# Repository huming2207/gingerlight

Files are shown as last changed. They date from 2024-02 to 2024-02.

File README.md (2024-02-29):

# GingerLight

Yet another CN5816-based LED boost driver board design for 36v 40w COB LED, like CREE CXB2540/3040/3540.

## Usage

- Provide a 20v, 2A DC input (e.g. from a USB PD charger)
- Hook up a 36v 40w LED, like CREE CXB2540/3040/3540 (I've tested with CREE CXB2540 for now), remember to put on a heatsink or otherwise it may become a bit smoky!
- It should work now

## Fine adjustments

- According to CN5816's official datasheet and component calculator:
- When `Vin` = **20v**, `Vled` = **36v**, `Iout` = **0.8A**:
  - 
  - If Vled goes too high, try reducing R1 to 4260kohm
- If you don't want it to be that bright, or you can't afford a big heatsink, then try increasing `R6` (the `Rsw`) to something like 0.2ohm.

## Caveats

According to Consonance FAE, when calculating the resistor divider for voltage threshold reference, the `Vout` here means `Vin` + `Vled`:



For example, my `Vin` is 20v, `Vled` (the LED's `Vf`) is 36v, then `Vout` needs to be 56v, not 36v.

## License 

CC-BY-NC-SA 4.0

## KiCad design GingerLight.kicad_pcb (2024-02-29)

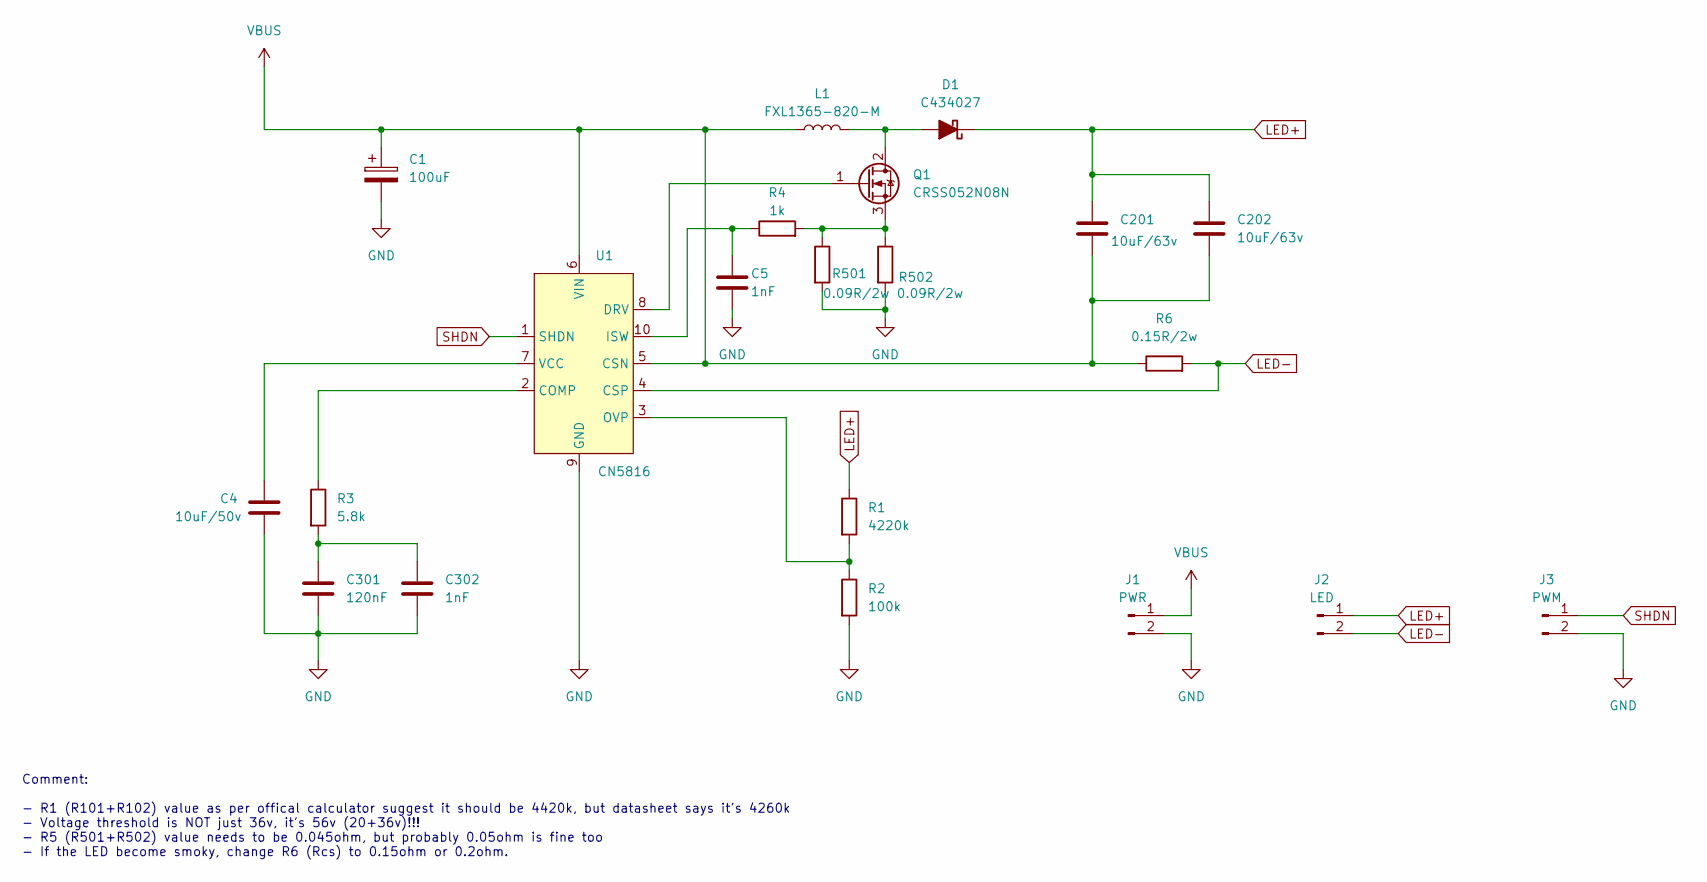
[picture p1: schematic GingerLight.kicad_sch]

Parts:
C1: 100uF; CP_Elec_8x10
C4: 10uF/50v; C_1206_3216Metric_Pad1.33x1.80mm_HandSolder
C5, C302: 1nF; C_0603_1608Metric_Pad1.08x0.95mm_HandSolder
C201, C202: 10uF/63v; C_1210_3225Metric_Pad1.33x2.70mm_HandSolder
C301: 120nF; C_0603_1608Metric_Pad1.08x0.95mm_HandSolder
D1: C434027; D_SMA
J1: PWR; PinHeader_1x02_P2.54mm_Vertical
J2: LED; PinHeader_1x02_P2.54mm_Vertical
J3: PWM; PinHeader_1x02_P2.54mm_Vertical
L1: FXL1365-820-M; L_TaiTech_TMPC1265_13.5x12.5mm
Q1: CRSS052N08N; TO-263-2
R1: 4220k; R_0603_1608Metric_Pad0.98x0.95mm_HandSolder
R2: 100k; R_0603_1608Metric_Pad0.98x0.95mm_HandSolder
R3: 5.8k; R_0603_1608Metric_Pad0.98x0.95mm_HandSolder
R4: 1k; R_0603_1608Metric_Pad0.98x0.95mm_HandSolder
R6: 0.15R/2w; R_2512_6332Metric_Pad1.40x3.35mm_HandSolder
R501, R502: 0.09R/2w; R_2512_6332Metric_Pad1.40x3.35mm_HandSolder
U1: CN5816; SSOP-10_3.9x4.9mm_P1.00mm

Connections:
GND: C1.2, C4.2, C5.2, C301.2, C302.2, J1.2, J3.2, R2.2, R501.2, R502.2, U1.9 (GND)
LED+: C201.1, C202.1, D1.1 (K), J2.1, R1.1
LED-: J2.2, R6.2, U1.4 (CSP)
unnamed: C301.1, C302.1, R3.2
unnamed: D1.2 (A), L1.2, Q1.2 (D)
unnamed: Q1.1 (G), U1.8 (DRV)
unnamed: Q1.3 (S), R4.2, R501.1, R502.1
unnamed: R3.1, U1.2 (COMP)
unnamed: C5.1, R4.1, U1.10 (ISW)
unnamed: R1.2, R2.1, U1.3 (OVP)
unnamed: C4.1, U1.7 (VCC)
SHDN: J3.1, U1.1 (SHDN)
VBUS: C1.1, C201.2, C202.2, J1.1, L1.1, R6.1, U1.5 (CSN), U1.6 (VIN)

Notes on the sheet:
Comment: - R1 (R101+R102) value as per offical calculator suggest it should be 4420k, but datasheet says it's 4260k - Voltage threshold is NOT just 36v, it's 56v (20+36v)!!! - R5 (R501+R502) value needs to be 0.045ohm, but probably 0.05ohm is fine too - If the LED become smoky, change R6 (Rcs) to 0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

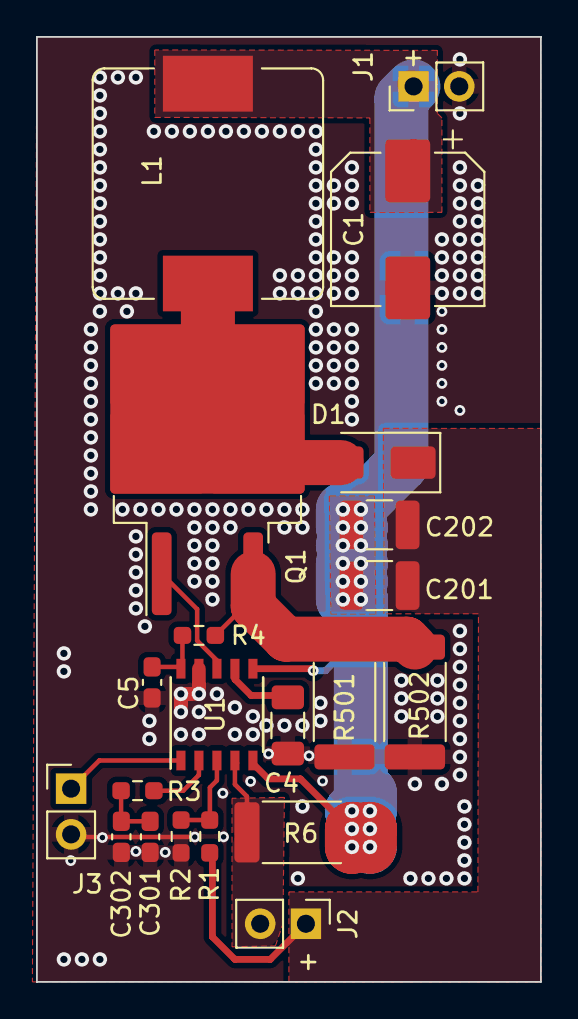
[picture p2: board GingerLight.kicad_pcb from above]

Board: 2 copper layers, 28.0 x 52.5 mm, 21 parts (0 on the bottom side), 13 nets.

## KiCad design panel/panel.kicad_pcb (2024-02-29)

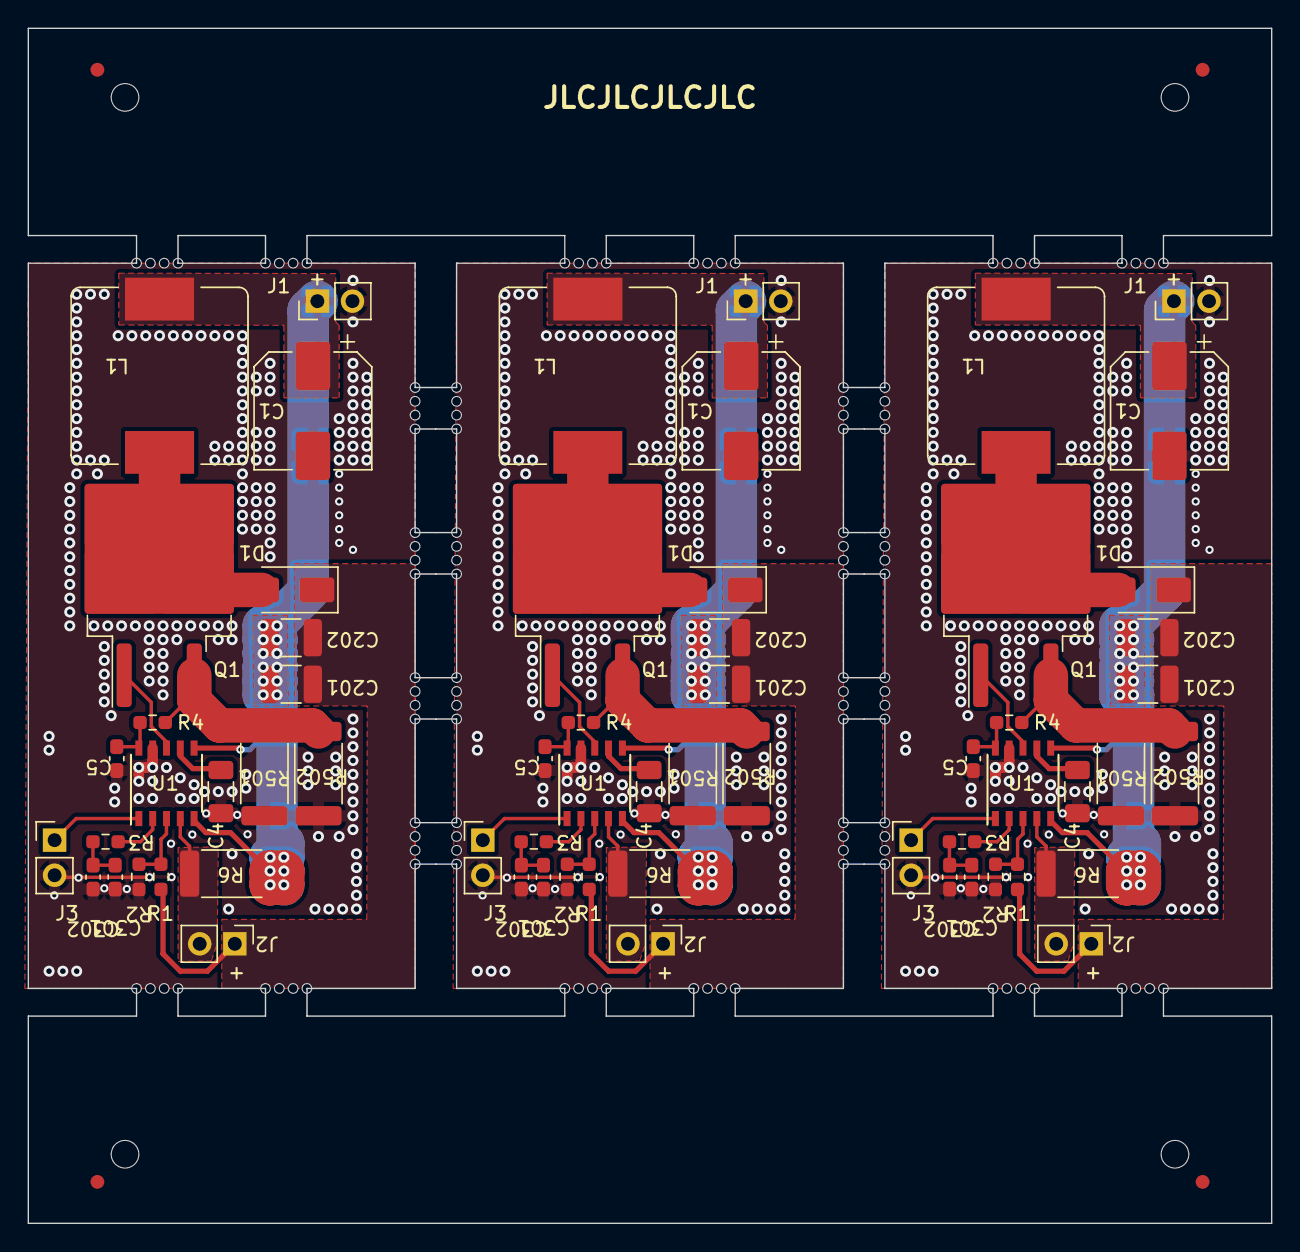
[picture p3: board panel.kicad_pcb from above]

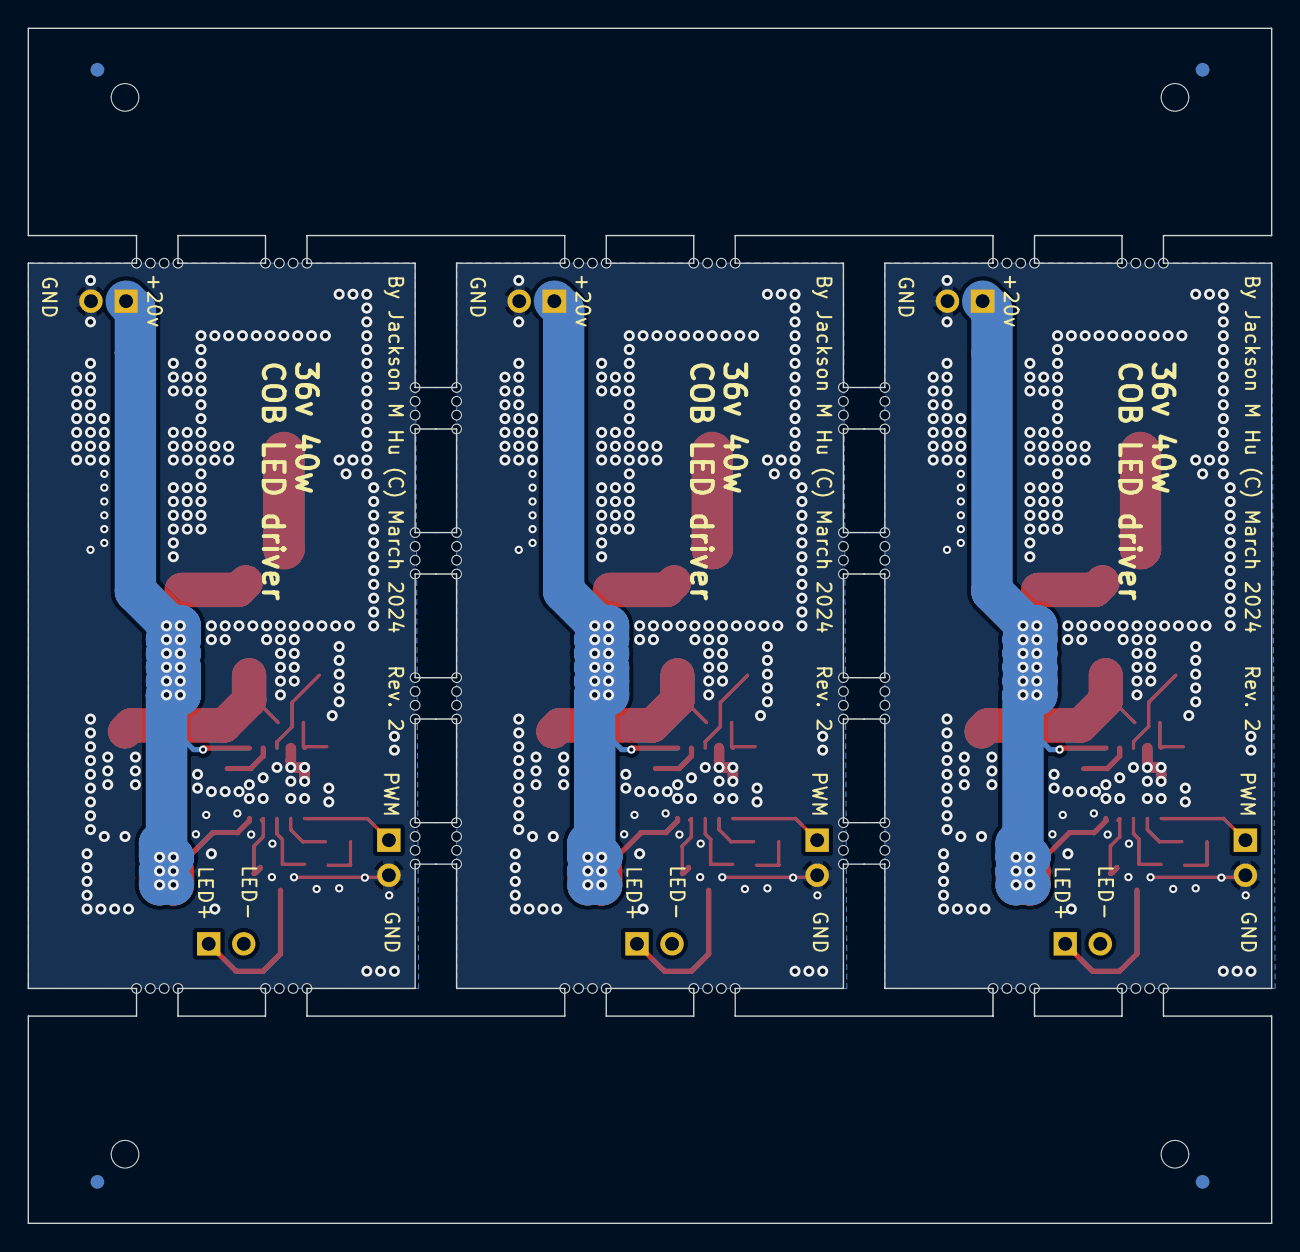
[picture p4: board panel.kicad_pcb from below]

Board: 2 copper layers, 90.0 x 86.5 mm, 187 parts (4 on the bottom side), 39 nets.

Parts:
C1, C1#2, C1#3: 100uF; CP_Elec_8x10
C4, C4#2, C4#3: 10uF/50v; C_1206_3216Metric_Pad1.33x1.80mm_HandSolder
C5, C5#2, C5#3, C302, C302#2, C302#3: 1nF; C_0603_1608Metric_Pad1.08x0.95mm_HandSolder
C201, C201#2, C201#3, C202, C202#2, C202#3: 10uF/63v; C_1210_3225Metric_Pad1.33x2.70mm_HandSolder
C301, C301#2, C301#3: 120nF; C_0603_1608Metric_Pad1.08x0.95mm_HandSolder
D1, D1#2, D1#3: C434027; D_SMA
J1, J1#2, J1#3: PWR; PinHeader_1x02_P2.54mm_Vertical
J2, J2#2, J2#3: LED; PinHeader_1x02_P2.54mm_Vertical
J3, J3#2, J3#3: PWM; PinHeader_1x02_P2.54mm_Vertical
KiKit_FID_B_1, KiKit_FID_B_2, KiKit_FID_B_3, KiKit_FID_B_4: Fiducial
KiKit_FID_T_1, KiKit_FID_T_2, KiKit_FID_T_3, KiKit_FID_T_4: Fiducial
KiKit_MB_1_1, KiKit_MB_1_2, KiKit_MB_1_3, KiKit_MB_1_4, KiKit_MB_2_1, KiKit_MB_2_2, KiKit_MB_2_3, KiKit_MB_2_4, KiKit_MB_3_1, KiKit_MB_3_2, KiKit_MB_3_3, KiKit_MB_3_4, KiKit_MB_4_1, KiKit_MB_4_2, KiKit_MB_4_3, KiKit_MB_4_4, KiKit_MB_5_1, KiKit_MB_5_2, KiKit_MB_5_3, KiKit_MB_5_4, KiKit_MB_6_1, KiKit_MB_6_2, KiKit_MB_6_3, KiKit_MB_6_4, KiKit_MB_7_1, KiKit_MB_7_2, KiKit_MB_7_3, KiKit_MB_7_4, KiKit_MB_8_1, KiKit_MB_8_2, KiKit_MB_8_3, KiKit_MB_8_4, KiKit_MB_9_1, KiKit_MB_9_2, KiKit_MB_9_3, KiKit_MB_9_4, KiKit_MB_10_1, KiKit_MB_10_2, KiKit_MB_10_3, KiKit_MB_10_4, KiKit_MB_11_1, KiKit_MB_11_2, KiKit_MB_11_3, KiKit_MB_11_4, KiKit_MB_12_1, KiKit_MB_12_2, KiKit_MB_12_3, KiKit_MB_12_4, KiKit_MB_13_1, KiKit_MB_13_2, KiKit_MB_13_3, KiKit_MB_13_4, KiKit_MB_14_1, KiKit_MB_14_2, KiKit_MB_14_3, KiKit_MB_14_4, KiKit_MB_15_1, KiKit_MB_15_2, KiKit_MB_15_3, KiKit_MB_15_4, KiKit_MB_16_1, KiKit_MB_16_2, KiKit_MB_16_3, KiKit_MB_16_4, KiKit_MB_17_1, KiKit_MB_17_2, KiKit_MB_17_3, KiKit_MB_17_4, KiKit_MB_18_1, KiKit_MB_18_2, KiKit_MB_18_3, KiKit_MB_18_4, KiKit_MB_19_1, KiKit_MB_19_2, KiKit_MB_19_3, KiKit_MB_19_4, KiKit_MB_20_1, KiKit_MB_20_2, KiKit_MB_20_3, KiKit_MB_20_4, KiKit_MB_21_1, KiKit_MB_21_2, KiKit_MB_21_3, KiKit_MB_21_4, KiKit_MB_22_1, KiKit_MB_22_2, KiKit_MB_22_3, KiKit_MB_22_4, KiKit_MB_23_1, KiKit_MB_23_2, KiKit_MB_23_3, KiKit_MB_23_4, KiKit_MB_24_1, KiKit_MB_24_2, KiKit_MB_24_3, KiKit_MB_24_4, KiKit_MB_25_1, KiKit_MB_25_2, KiKit_MB_25_3, KiKit_MB_25_4, KiKit_MB_26_1, KiKit_MB_26_2, KiKit_MB_26_3, KiKit_MB_26_4, KiKit_MB_27_1, KiKit_MB_27_2, KiKit_MB_27_3, KiKit_MB_27_4, KiKit_MB_28_1, KiKit_MB_28_2, KiKit_MB_28_3, KiKit_MB_28_4: NPTH
KiKit_TO_1, KiKit_TO_2, KiKit_TO_3, KiKit_TO_4: NPTH
L1, L1#2, L1#3: FXL1365-820-M; L_TaiTech_TMPC1265_13.5x12.5mm
Q1, Q1#2, Q1#3: CRSS052N08N; TO-263-2
R1, R1#2, R1#3: 4220k; R_0603_1608Metric_Pad0.98x0.95mm_HandSolder
R2, R2#2, R2#3: 100k; R_0603_1608Metric_Pad0.98x0.95mm_HandSolder
R3, R3#2, R3#3: 5.8k; R_0603_1608Metric_Pad0.98x0.95mm_HandSolder
R4, R4#2, R4#3: 1k; R_0603_1608Metric_Pad0.98x0.95mm_HandSolder
R6, R6#2, R6#3: 0.15R/2w; R_2512_6332Metric_Pad1.40x3.35mm_HandSolder
R501, R501#2, R501#3, R502, R502#2, R502#3: 0.09R/2w; R_2512_6332Metric_Pad1.40x3.35mm_HandSolder
U1, U1#2, U1#3: CN5816; SSOP-10_3.9x4.9mm_P1.00mm

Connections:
Board_0-GND: C1#3.2, C4.2, C5#3.2, C301#3.2, C302#3.2, J1.2, J3#2.2, R2#3.2, R501#2.2, R502#3.2, U1#2.9 (GND)
Board_0-LED+: C201.1, C202#3.1, D1#2.1 (K), J2#3.1, R1#2.1
Board_0-LED-: J2#3.2, R6#3.2, U1#2.4 (CSP)
Board_0-Net-(C301-Pad1): C301#3.1, C302#3.1, R3#3.2
Board_0-Net-(D1-A): D1#2.2 (A), L1#3.2, Q1#3.2 (D)
Board_0-Net-(Q1-G): Q1#3.1 (G), U1#2.8 (DRV)
Board_0-Net-(Q1-S): Q1#3.3 (S), R4#3.2, R501#2.1, R502#3.1
Board_0-Net-(U1-COMP): R3#3.1, U1#2.2 (COMP)
Board_0-Net-(U1-ISW): C5#3.1, R4#3.1, U1#2.10 (ISW)
Board_0-Net-(U1-OVP): R1#2.2, R2#3.1, U1#2.3 (OVP)
Board_0-Net-(U1-VCC): C4.1, U1#2.7 (VCC)
Board_0-SHDN: J3#2.1, U1#2.1 (SHDN)
Board_0-VBUS: C1#3.1, C201.2, C202#3.2, J1.1, L1#3.1, R6#3.1, U1#2.5 (CSN), U1#2.6 (VIN)
Board_1-GND: C1.2, C4#3.2, C5.2, C301.2, C302.2, J1#3.2, J3#3.2, R2.2, R501.2, R502.2, U1.9 (GND)
Board_1-LED+: C201#3.1, C202.1, D1#3.1 (K), J2#2.1, R1#3.1
Board_1-LED-: J2#2.2, R6.2, U1.4 (CSP)
Board_1-Net-(C301-Pad1): C301.1, C302.1, R3.2
Board_1-Net-(D1-A): D1#3.2 (A), L1#2.2, Q1.2 (D)
Board_1-Net-(Q1-G): Q1.1 (G), U1.8 (DRV)
Board_1-Net-(Q1-S): Q1.3 (S), R4#2.2, R501.1, R502.1
Board_1-Net-(U1-COMP): R3.1, U1.2 (COMP)
Board_1-Net-(U1-ISW): C5.1, R4#2.1, U1.10 (ISW)
Board_1-Net-(U1-OVP): R1#3.2, R2.1, U1.3 (OVP)
Board_1-Net-(U1-VCC): C4#3.1, U1.7 (VCC)
Board_1-SHDN: J3#3.1, U1.1 (SHDN)
Board_1-VBUS: C1.1, C201#3.2, C202.2, J1#3.1, L1#2.1, R6.1, U1.5 (CSN), U1.6 (VIN)
Board_2-GND: C1#2.2, C4#2.2, C5#2.2, C301#2.2, C302#2.2, J1#2.2, J3.2, R2#2.2, R501#3.2, R502#2.2, U1#3.9 (GND)
Board_2-LED+: C201#2.1, C202#2.1, D1.1 (K), J2.1, R1.1
Board_2-LED-: J2.2, R6#2.2, U1#3.4 (CSP)
Board_2-Net-(C301-Pad1): C301#2.1, C302#2.1, R3#2.2
Board_2-Net-(D1-A): D1.2 (A), L1.2, Q1#2.2 (D)
Board_2-Net-(Q1-G): Q1#2.1 (G), U1#3.8 (DRV)
Board_2-Net-(Q1-S): Q1#2.3 (S), R4.2, R501#3.1, R502#2.1
Board_2-Net-(U1-COMP): R3#2.1, U1#3.2 (COMP)
Board_2-Net-(U1-ISW): C5#2.1, R4.1, U1#3.10 (ISW)
Board_2-Net-(U1-OVP): R1.2, R2#2.1, U1#3.3 (OVP)
Board_2-Net-(U1-VCC): C4#2.1, U1#3.7 (VCC)
Board_2-SHDN: J3.1, U1#3.1 (SHDN)
Board_2-VBUS: C1#2.1, C201#2.2, C202#2.2, J1#2.1, L1.1, R6#2.1, U1#3.5 (CSN), U1#3.6 (VIN)

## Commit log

2024-02-15 Rev 1
    [GingerLight.kicad_pcb, GingerLight.kicad_sch]
2024-02-16 Rev 1.1
    [GingerLight.kicad_pcb, GingerLight.kicad_sch]
2024-02-29 Rev 2
    [GingerLight.kicad_pcb, GingerLight.kicad_sch]
2024-02-29 Rev 2: add panel & gerber
    [GingerLight-CmtUser.gbr, GingerLight-CuBottom.gbl, GingerLight-CuTop.gtl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]
